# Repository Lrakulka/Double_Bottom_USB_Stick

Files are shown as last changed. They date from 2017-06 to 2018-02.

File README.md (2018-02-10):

# Double Bottom USB Stick
USB Stick that can conceal and encrypt its partitions. **The project is 100% student work.** 

The project meets all goals and fully operational. However, during the development was proposed improvements that were not implemented. We recommend to visit category [Future Improvements](https://github.com/Lrakulka/Double_Bottom_USB_Stick#future-improvements).

[Google Summer of Code 2017](https://summerofcode.withgoogle.com/archive/2017/projects/5906524656369664/)

Student: Oleksandr Borysov

Project Name: USB Flash Drive with possibility to conceal information (Double Bottom USB Stick)

Organization: Portland State University

Mentor: Keith Packard

Most of the work was done in the files sd_io_controller.\* and user_interface.\*
# Project Brief
The main goal of the project is the creation of USB Flash Drive with the possibility to conceal the fact that the flash drive contains hidden information. It means that hidden folders and files will not be displayed if the USB drive is connected to computer. The microcontroller of the Double Bottom USB Stick will carry the process of encryption and concealment of files and folders. 

The only possibility to break protection is physically read a memory from the memory component and breaking the encryption algorithm.

# Demonstration Video
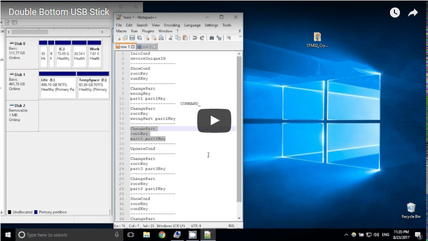
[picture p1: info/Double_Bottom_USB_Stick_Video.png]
(https://youtu.be/NDC2jo4gk50)
;

# Installation Instruction
1) Download and install [ST-Link](http://www.st.com/content/st_com/en/products/embedded-software/development-tool-software/stsw-link009.html);
2) Download and install [TRUEStudio](https://atollic.com/truestudio/);
3) Download and install [STM32CubeMX v4.18](https://community.st.com/thread/39835-please-provide-a-way-to-download-older-version-of-the-cube);
4) Clone the project or download zip file;
5) Open CubeMX project file ```Double_Bottom_USB_Stick.ioc```;
6) Generate STM source code (Button with Gear);
7) Open the project in the command prompt;
8) Execute command: ```git apply --reject --whitespace=fix Patch-for-STM-files.patch```;
9) Delete the directory ```Double_Bottom_USB_Stick\Middlewares\Third_Party\FatFs\src\drivers``` in the project;
10) Open TRUEStudio. Select File -> Import... -> General -> Existing Project into Workspace -> Press "Next >" button -> Browse to the project folder -> Select "Double_Bottom_USB_Stick" in the Project window -> Press "Finish";
11) Connect  the board to the PC;
12) Select in the project explorer one of the project's files and press "Debug" (Button with Green bug)

# Project Technologies And Hardware
* Test board is NUCLEO [STM32F446RE](https://developer.mbed.org/platforms/ST-Nucleo-F446RE/);
* SDIO Micro SD Card reader module;
* FS USB 2.0 cable;
* Micro SD 4 GB class 4, HC;
* A large part of the project generated with help of STM32CubeMX v4.18 Firmware v1.14 ([Cube project file](https://github.com/Lrakulka/Double_Bottom_USB_Stick/blob/master/Double_Bottom_USB_Stick.ioc));
* TRUEStudio was used for the project development;
* Dependiaces: SDIO intarface, FS USB 2.0 Mass Storage Device intaface, [FatFS](http://elm-chan.org/fsw/ff/00index_e.html)
# Board Schematic
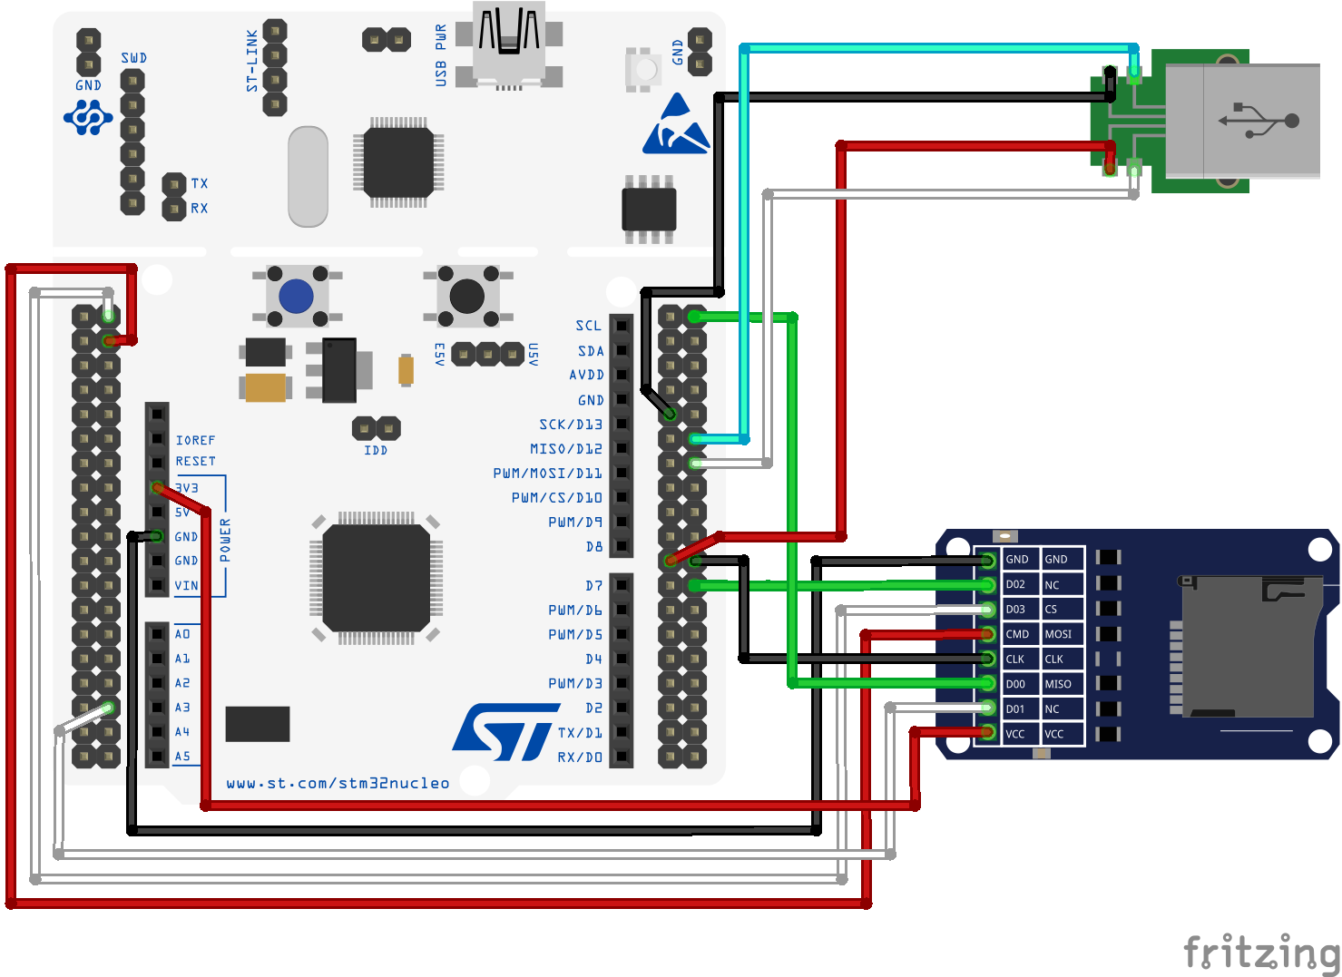
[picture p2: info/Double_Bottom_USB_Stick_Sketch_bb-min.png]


# How It Works
The logic behind the device is to represent a part of SD Card memory as the solid memory of the device (Double Bottom USB Stick).
The project present itself as regular USB Mass Storage Device (USB 2.0 Stick) and currently visible partition memory represents as USB Stick memory to the host. Zero partition is always public because this partition displays when the device physically connected to the host. Also, this partition will be demonstrated to the user if connect SD Card without the device to the host. The partitions divided into two categories: public and private. The private partitions are encrypted/decrypted by XOR cipher on the fly using the partition key. 
The device configurations encryption/decryption by AES cipher at the saving/loading configurations to/from the SD Card using the root key.
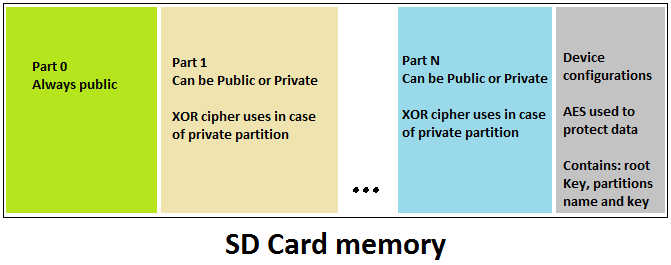
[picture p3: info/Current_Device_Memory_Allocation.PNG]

# User Commands
Currently, the device supports four commands:
* Initializes device default configurations (```InitConf - INIT_DEVICE_CONFIGURATIONS```)
* Changes currently visible partition (```ChangePart - CHANGE_PARTITION```)
* Shows device configurations (```ShowConf - SHOW_ROOT_CONFIGURATIONS```)
* Updates device configurations (```UpdateConf - UPDATE_ROOT_CONFIGURATIONS```)

### InitConf ###
Create a file with name ```COMMAND_.TXT - COMMAND_FILE_NAME``` in the root directory of the device and fill it with the following text.
```
InitConf
[Device Unique ID - DEVICE_UNIQUE_ID]
// Empty line
```
If device ID is correct then the command file will be deleted and the device will reconnect to the host, if ID or command not correct no action will be executed.

### ChangePart ###
Create a file with name ```COMMAND_.TXT - COMMAND_FILE_NAME``` in the root directory of the device and fill it with the following text.
```
ChangePart
[Device root key]
[Partition name] [Partition key]
// Empty line
```
If root key, partition key and partition name are correct then the command file will be deleted and the device will reconnect to the host and switch the currently visible partition. If root key not correct no action will be executed. If the partition name or key is incorrect then the command file will be renamed to ```COMMAND_FILE_NAME_FAILED - COMMANDF.TXT``` (If the partition is public then You should write "public" as partition key).

### ShowConf ###
Create a file with name ```COMMAND_.TXT - COMMAND_FILE_NAME``` in the root directory of the device and fill it with the following text.
```
ShowConf
[Device root key]
[Configurations key]
// Empty line
```
If device root key and configuration key are correct then the command file will be deleted and the device will reconnect to the host and will create a file ```DEVICE_CONFIGS - CONFIGS_.TXT``` with the device configurations. If the root key or configuration key is not correct then no action will be executed.

### UpdateConf ###
Create a file with name ```COMMAND_.TXT - COMMAND_FILE_NAME``` in the root directory of the device and fill it with the following text.
```
UpdateConf
[Device root key]
[Configurations key]
[New configurations key] <--- Key for revealing device configurations
[New device root key] <--- Root Key of the device
#N___________Name___________Key___________Number of sectors
0  part0                public               3872257   
1  part1                part1Key             3870000  
2  part2                part2Key             2000  
3  part3                part3Key             253  
[New partition number] [New partition name] [New partition key] [New partition memory size]
-------------SD card available memory-------------
3965190144          <- Card capacity memory	
512                 <- Card block size	
7744510             <- Card block sector number	
// Empty line
```
Note: if write "public" as [New partition key] the partition will be public. Also you can delete partitions as well (Just delete it from the update configuration file).

If device root key and configuration key are correct the command file will be deleted and the device will reconnect to the host and the device configurations will be updated, also the currently visible partition will be switched to partition 0. If the root key or configuration key is not correct then no action will be executed. If update operation fails with error the command file will be renamed to ```COMMAND_FILE_NAME_FAILED - COMMANDF.TXT```.

Note 1: Any commands that failed with an error during execution will rename the command file to  ```COMMAND_FILE_NAME_FAILED - COMMANDF.TXT```.
Note 2: The project has constants that created for debug mode ```DEBUG_MOD``` and ```CIPHER_MOD```(Constans change behavior of the device)
# Future Improvements
At this moment each partition part of SD Card memory is allocated as a solid piece. This approach would be acceptable if the project used AES encryption for the partition but due to its performance costs the device uses XOR cipher. That is why spreading the memory of each partition across the SD Card memory will increase the level of data protection. Also, the logic BEHIND forming long XOR key must be more complex to increase XOR cipher reliability.
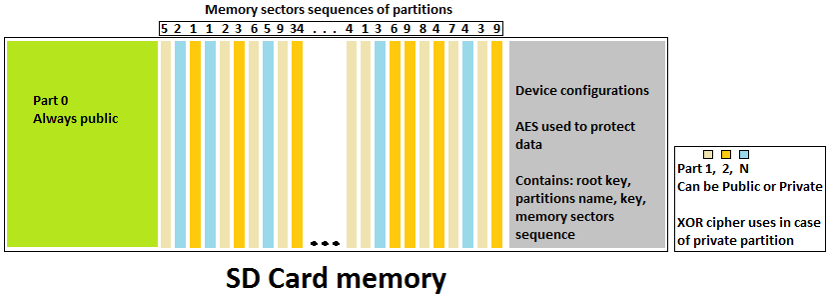
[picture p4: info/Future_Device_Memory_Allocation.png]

# My Test Board
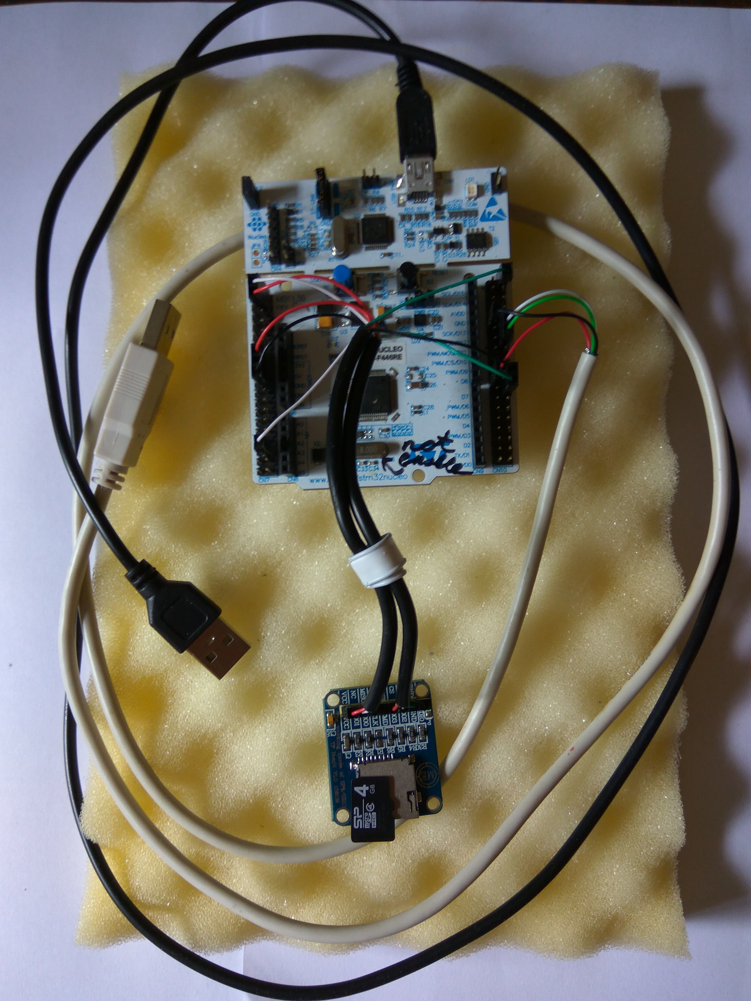
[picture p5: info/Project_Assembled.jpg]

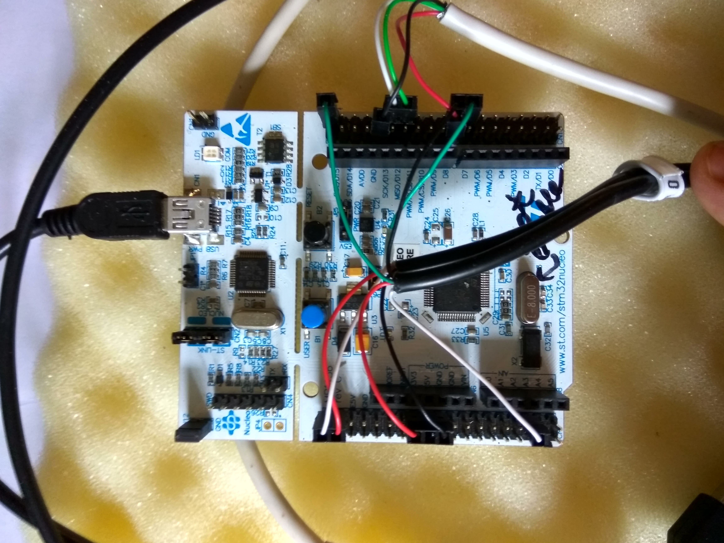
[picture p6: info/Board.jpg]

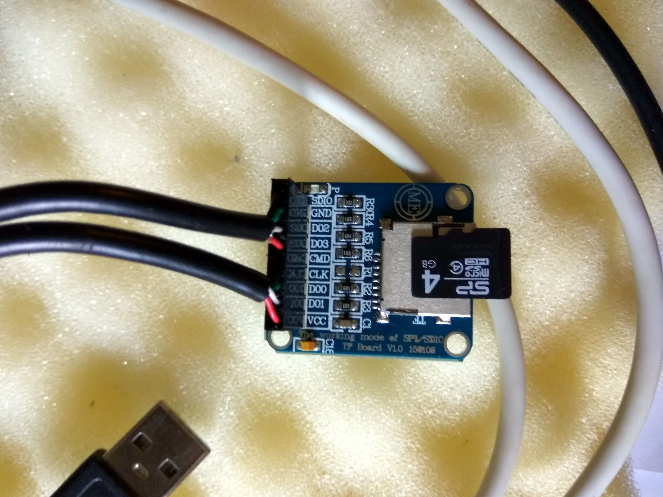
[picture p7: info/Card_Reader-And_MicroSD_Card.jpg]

# More
The project [issues](https://github.com/Lrakulka/Double_Bottom_USB_Stick/issues) contains useful information related to the project.

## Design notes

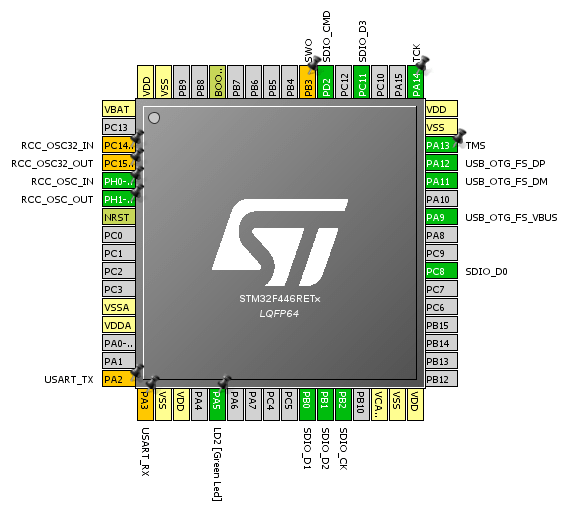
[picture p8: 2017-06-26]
info/Microcontroller_Pinout-min.PNG

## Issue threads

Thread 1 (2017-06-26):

DB-002: Slow data transfer

Lrakulka, 2017-06-26:
Original data reading from the SD Card
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
Original data writing on the SD Card
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
The project speeed of data reading
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
The project speed of data writing
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
The tests used the same SD Card

Lrakulka, 2017-07-09:
I use DMA to solve this problem, but the speed has changed only a bit for reading.
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

Lrakulka, 2017-08-06:
Solution:
https://community.st.com/message/164765-sdio-dma-fatfs-usb-hs-slow-data-transfer#comments

Reading speed
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
Writing speed
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

Closed 2017-08-06.

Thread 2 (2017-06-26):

SD Card module issue

Lrakulka, 2017-06-26:
The project Micro SD Card module reader has a problem with some SD cards.

Lrakulka, 2017-06-28:
After searching I figure out that the problem was caused by a resistor on CLK line.
The solution is to remove that resistor from the module.
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

Closed 2017-07-04.

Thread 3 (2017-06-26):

USB cable with wrong colors of wires

Lrakulka, 2017-06-26:
It happened so that I was unlucky to get a USB 2.0 cable with the wrong color marking of the wires.

The marking should be as described below.
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
But I got this
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

Lrakulka, 2017-06-28:
The obvious solution is to change the places of the wires, but if you do not expect something like that from the production, then this can be a real headache for you.

Lrakulka, 2017-07-04:
The schematic which I used can be wrong because I found other schematics which describes pinout in another way that is why I recommend to check pins of the cable with the multimeter.

Closed 2017-07-04.

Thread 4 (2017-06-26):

STM32f4 USB interface activation pin

Lrakulka, 2017-06-26:
The USB interface is not activated without activating the activation pin.

Lrakulka, 2017-07-26:
Beginning from the fourth generation of STM32 microcontrollers enabling of VBUS pin is mandatory. Even if you disabled this option from the software the interface will not work because the pin not activated.

Solution:
1) Enable VBUS option
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
2) Put the voltage on this pin to activate it

Closed 2017-07-26.

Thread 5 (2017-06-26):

SD Card module voltage issue

Lrakulka, 2017-06-26:
The SD Card doesn't want to work from the 5V supply.

Lrakulka, 2017-07-09:
The information of my SD Card module says that it can work on 5V or 3.3V but experiment showed that it depends on the SD Card.
In my case, it's 3.3V.

Closed 2017-07-09.

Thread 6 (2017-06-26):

STM32CubeMX old tutorials

Lrakulka, 2017-06-26:
The last update (14-April-2017) has changed a lot in CubeMX v1.21 and Firmware Package v1.16.0 at least in the SDIO module. That is why a lot of tutorials are not sufficient anymore.
But you still can download an older version and work with it.

Lrakulka, 2017-07-09:
You can find older versions [here](https://community.st.com/thread/39835-please-provide-a-way-to-download-older-version-of-the-cube)

Closed 2017-07-09.

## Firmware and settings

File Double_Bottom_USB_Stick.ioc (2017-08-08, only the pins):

Mcu.UserName=STM32F446RETx
PA11.Signal=USB_OTG_FS_DM
PA12.Signal=USB_OTG_FS_DP
PA13.GPIO_Label=TMS
PA13.Signal=SYS_JTMS-SWDIO
PA14.GPIO_Label=TCK
PA14.Signal=SYS_JTCK-SWCLK
PA2.GPIO_Label=USART_TX
PA2.Signal=USART2_TX
PA3.GPIO_Label=USART_RX
PA3.Signal=USART2_RX
PA5.GPIO_Label=LD2 [Green Led]
PA5.Signal=GPIO_Output
PA9.Signal=USB_OTG_FS_VBUS
PB0.Signal=SDIO_D1
PB1.Signal=SDIO_D2
PB2.Signal=SDIO_CK
PB3.GPIO_Label=SWO
PB3.Signal=SYS_JTDO-SWO
PC11.Signal=SDIO_D3
PC13.GPIO_Label=B1 [Blue PushButton]
PC13.Signal=GPXTI13
PC14-OSC32_IN.Signal=RCC_OSC32_IN
PC15-OSC32_OUT.Signal=RCC_OSC32_OUT
PC8.Signal=SDIO_D0
PD2.Signal=SDIO_CMD
PH0-OSC_IN.Signal=RCC_OSC_IN
PH1-OSC_OUT.Signal=RCC_OSC_OUT

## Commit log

2017-06-26 Init commit
    The old project on ChibiOS was replaced by current project on FreeRTOS because
    of advantages of FreeRTOS
    [Double_Bottom_USB_Stick.ioc]
2017-06-26 Images for the readme file
    [Double_Bottom_USB_Stick_Sketch.fzz]
2017-07-02 Updated schematic of the project
    [Double_Bottom_USB_Stick_Sketch.fzz]
2017-07-05 DB-001: Fix for SD card read only mode
    Problem was fixed by decrising STM32CubeF4 Firmware Package V1.16.0 version to V1.12.0
    [Double_Bottom_USB_Stick.ioc]
2017-07-08 DB-002: The project was moved to use CubeMX v1.18 and framework v1.14
2017-07-09 SDIO FatFS DMA initialization
2017-07-10 DMA priority changed to Very High
2017-07-11 DMA configuration for USB intarface
    Test DMA with SD Card
2017-07-11 Solved issue in the FatFS driver library with DMA
2017-07-12 DMA init
2017-07-15 Default FatFs connector to SD Card added to ignored files
2017-07-17 Added simple interface for users for switching partitions
2017-07-23 Whith new configs the device swith partition to partition number 0:
2017-07-25 The issue with storage solved
    The issue was caused by not enough of stack memory
    [Double_Bottom_USB_Stick.ioc]
2017-07-27 Partitions switching demonstration
2017-08-11 Added time interrupt
    Folder scan for the command file
2017-08-11 Interrupt timer resets when USB active
2017-08-13 Device capacity(Partition)
    If configurations not initialized device sets capacity using the file
    system if it's fails the capacity sets by SD card capacity
2017-08-13 Load the device configuration from the SD card
2017-08-16 The device reinit USB connection to show the conf file
2017-08-18 Fixed issue that may fail USB initialization
    Issue description. During update of the device configuration USB interface initialization
    could be failed because of wrong new configurations
2017-08-18 Partition key checks before switching the partition
2017-08-19 Fixed the command file rename after failed partition switch
2017-08-19 Fixed capacity calculation
2017-08-22 Device memory allocation
2017-08-23 Removed command file
    Solved issues with the command file removing after success partition
    switching
